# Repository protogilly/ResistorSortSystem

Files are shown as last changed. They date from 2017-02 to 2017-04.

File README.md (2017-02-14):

# ResistorSortSystem
Resistor Sortation System Codebase and Documentation

## Synopsis

This repository contains all the code for my Senior Project, which was a Resistor Sortation System. The finished project accepts resistors within a certain level of straightness at the input, sends them through a stepper-driven feeder that orients and centers them. Next, a servo presses contacts down onto the resistor leads and the machine steps through a ranging process to find the proper configuration to measure the resistor accurately and the contacts are released. After the resistor value is known, a stepper underneath a wheel with receptacles drives until the proper cup is under the dispensing chute. Then another servo is triggered that opens a swing arm releasing the resistor down the chute and into the receptacle.

## Utility to Others

The code in this project contains several snippets that may be useful to users in the future. This project was put on GitHub to make versioning easier for myself, but ultimately will be left online for this purpose. I expect that others may run into similar issues in the future and will attempt to make the code as well-documented as possible for an outsider perspective.

## Motivation

The initial project concept came from seeing containers in one of the University of Memphis’s Engineering Technology labs filled with a of jumbled pile of misshapen resistors of unknown values and wattage ratings with tangled leads. 

This project presented an interesting and challenging Senior Project opportunity, as well as a way to create something useful for both the University Labs and my own personal electronics lab. 

## Platform

The project consists of four parts.

 1. Scripts that run on a Raspberry Pi which speak with controllers on the mainboard over Serial.
 2. The primary program, which runs on a Teensy 3.2. This drives servos, issues commands for steppers, measures resistors, and contains logic that relates these commands to eachother.
 3. A Program that runs on one ATTiny84A which controls the feed stepper. This controller is slaved to the Teensy over I2C and accepts simple commands.
 4. A program that runs on the other ATTiny84A which controls the sort wheel. This controller is also slaved to the Teensy over I2C.

The Raspberry Pi portion is not yet coded, but will be implemented in either Python or C++.
All microcontroller portions are coded using the Arduino codebase and whatever extra drivers are needed for each microcontroller (for example, Teensyduino for the Teensy 3.2).

## Contributors

Until this project is completed at the end of this semester, no external contributors will be allowed. You can, of course, fork the project, but I cannot offer any reasonable support for the project until it has reached a certain state of completion.

## License

This project has no license at the current time. After completion, I will likely move parts of the project into an Open license of some kind, but that is not yet determined.

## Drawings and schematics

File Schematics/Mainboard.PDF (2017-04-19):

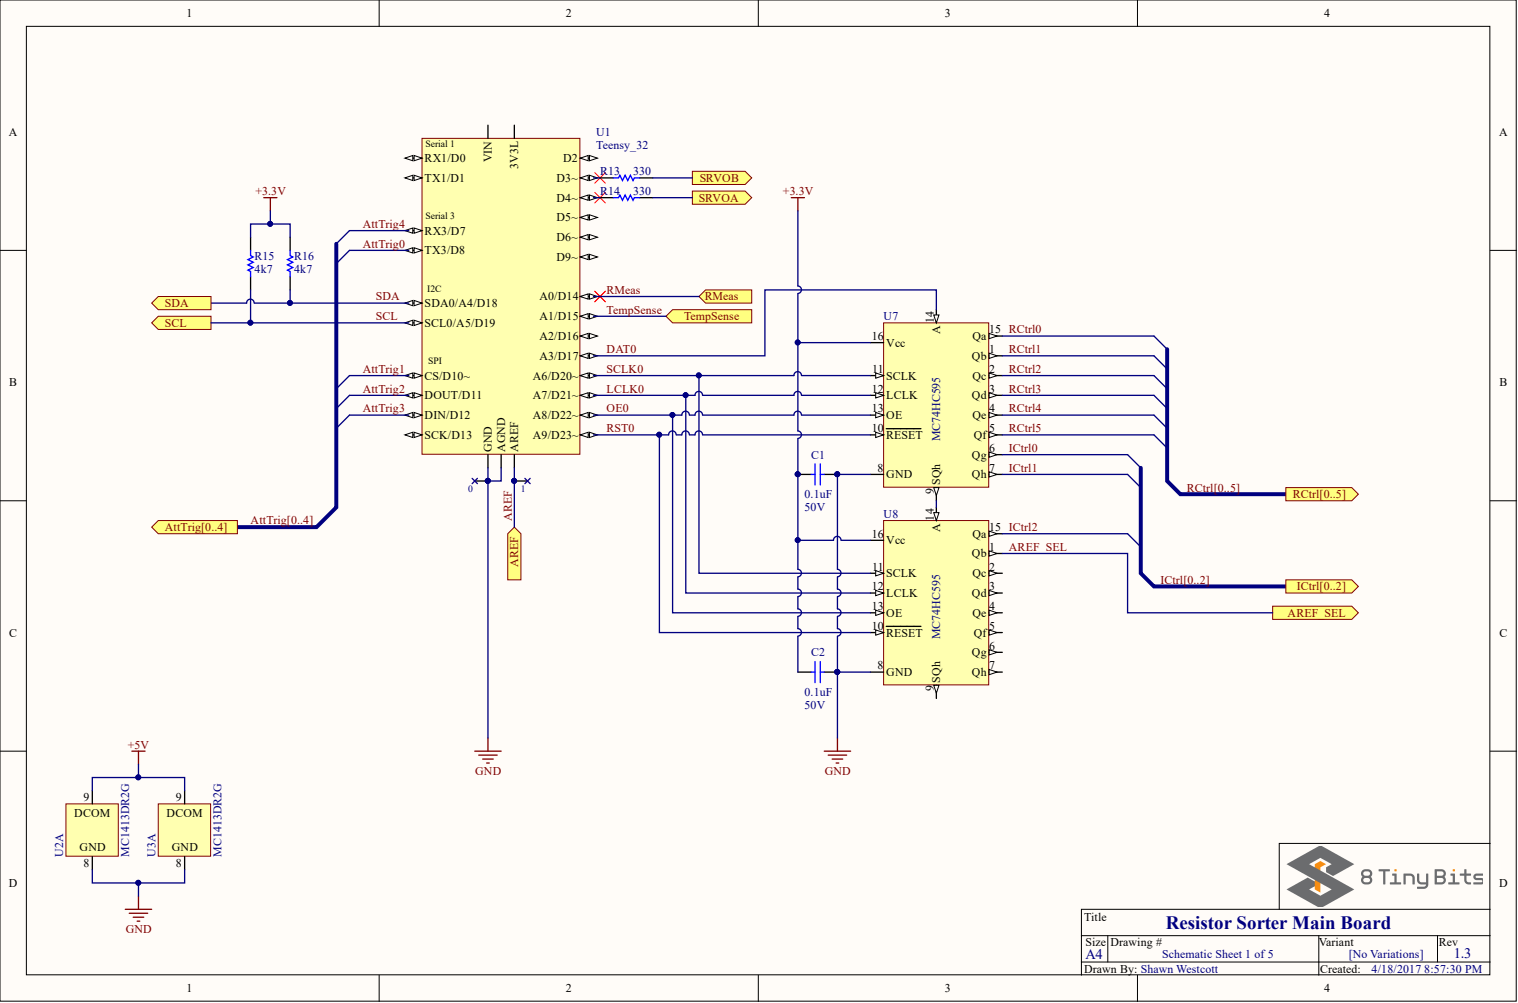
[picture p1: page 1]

Vcc | Q c Q d Q e Q f Q g Q h

SCL K 0 | 1 1 | SCL K LCL K O E RESE T G N D
LCL K 0 | | | 1 2
O E 0 | | | | 1 3
RST 0 | | | | | 1 0

1 1
1 2 | 3
1 3 | 4
1 0

2 | ICtrl[0..2 ]

Draw i n g # Schemat ic Sheet 1 of 5 | Varian t [N o Variat s ]

Created / : 0 PM

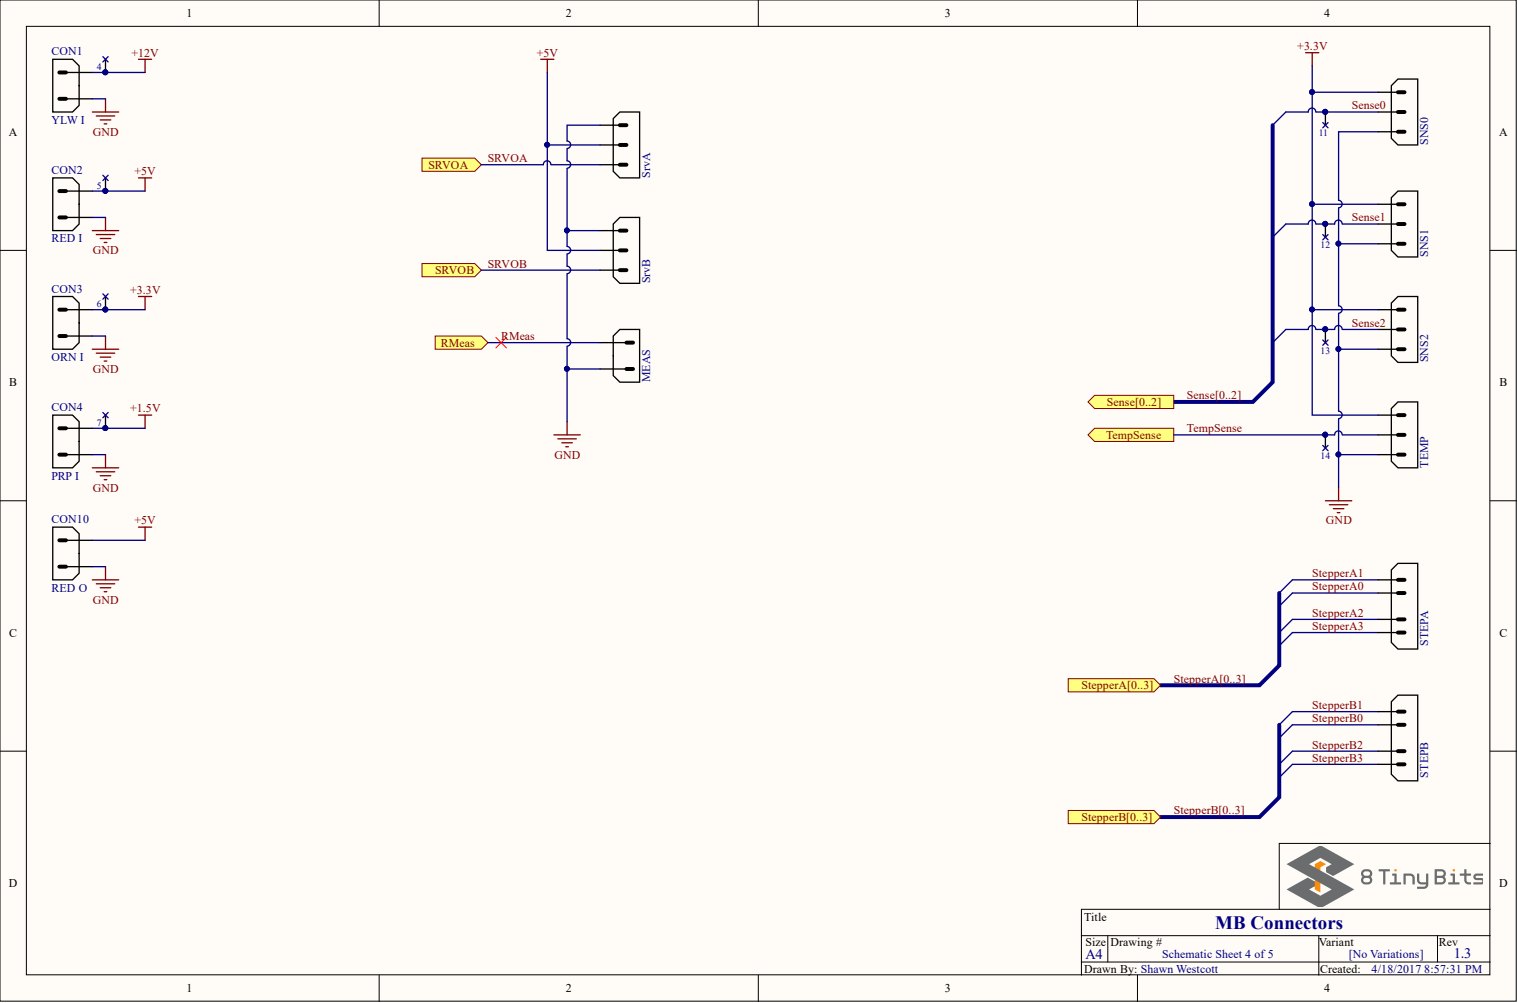
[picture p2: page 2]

MB Connectors Varian

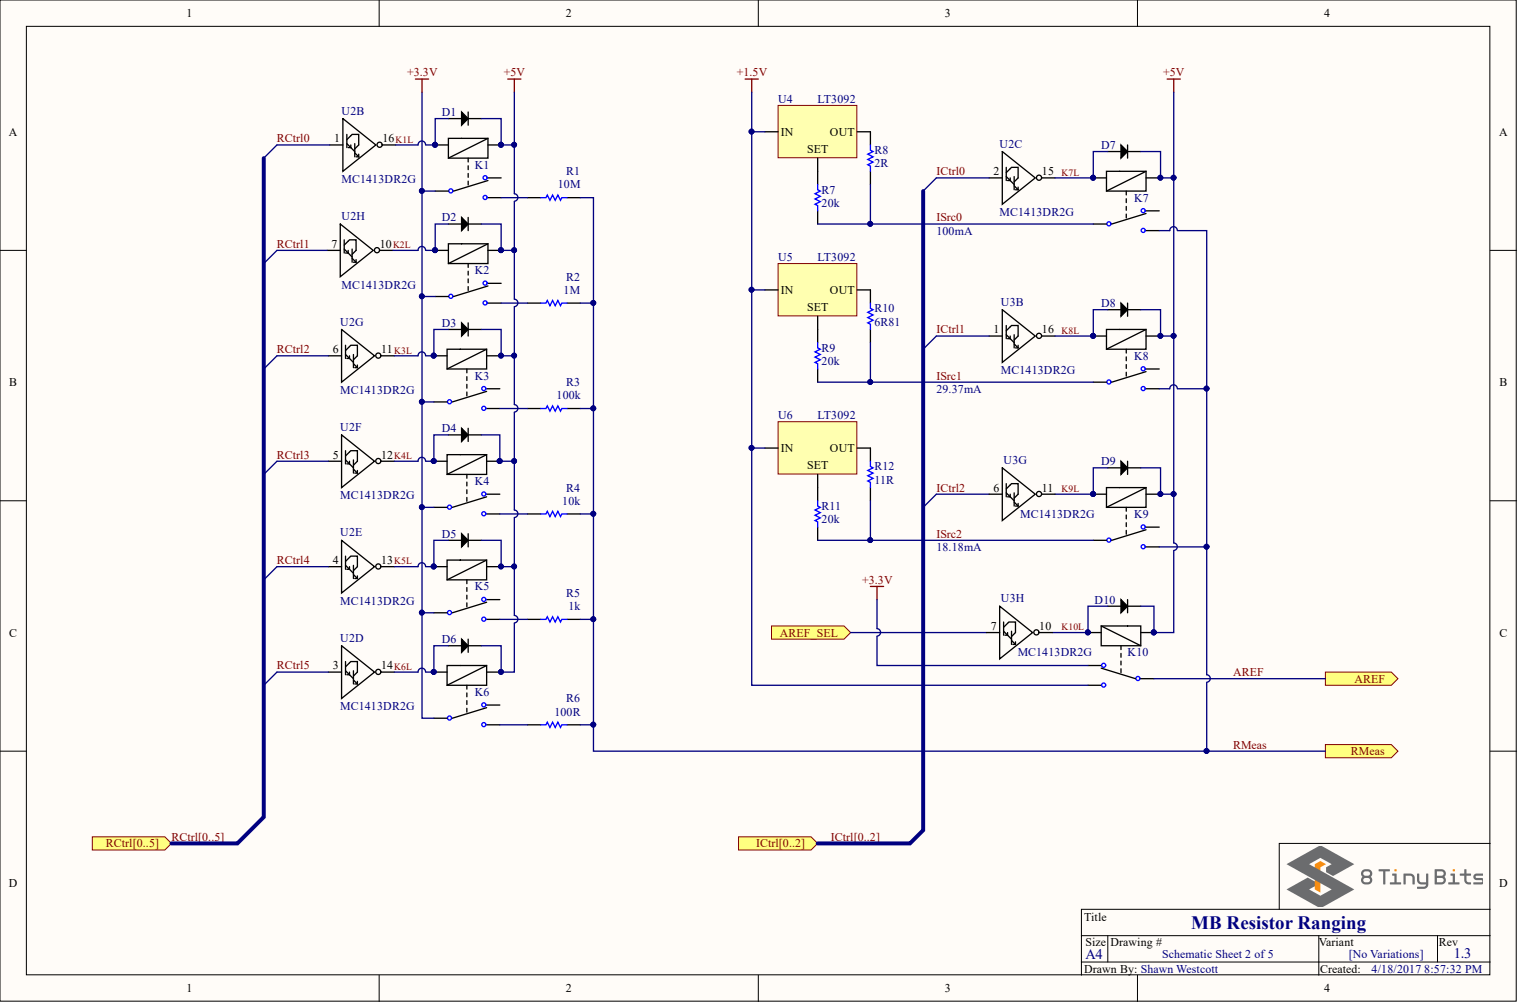
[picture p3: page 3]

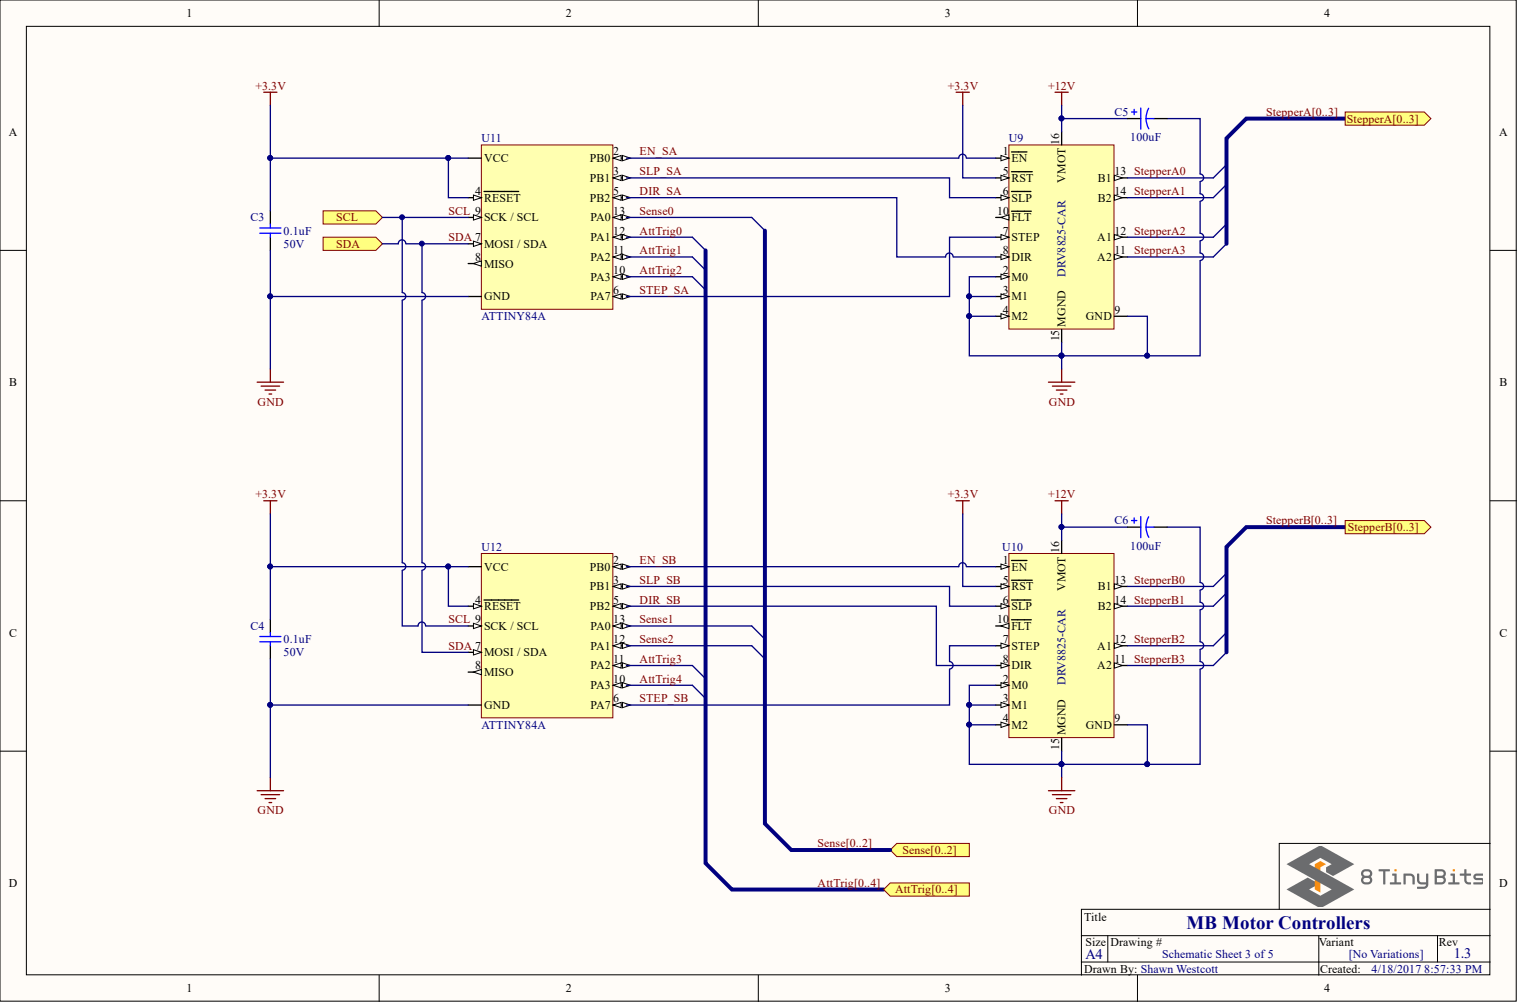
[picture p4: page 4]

SLP_SA | | RST 5
DIR_SA | SLP 6

SDA | MOSI / SDA 7 | | STEP 7

MISO 8

AttTrig1 | DIR 8
AttTrig2 | M0 2

SLP_SB | | RST 5
DIR_SB | SLP 6

AttTrig4 STEP_SB | M0 2

M1 3
M2 4

Size A4 | Schematic Sheet 3 of 5 | Variant [No Variations] | Rev 1.3 Drawing #

Drawn By: Shawn Westcott | | Created: 4/18/2017 8:57:33 PM

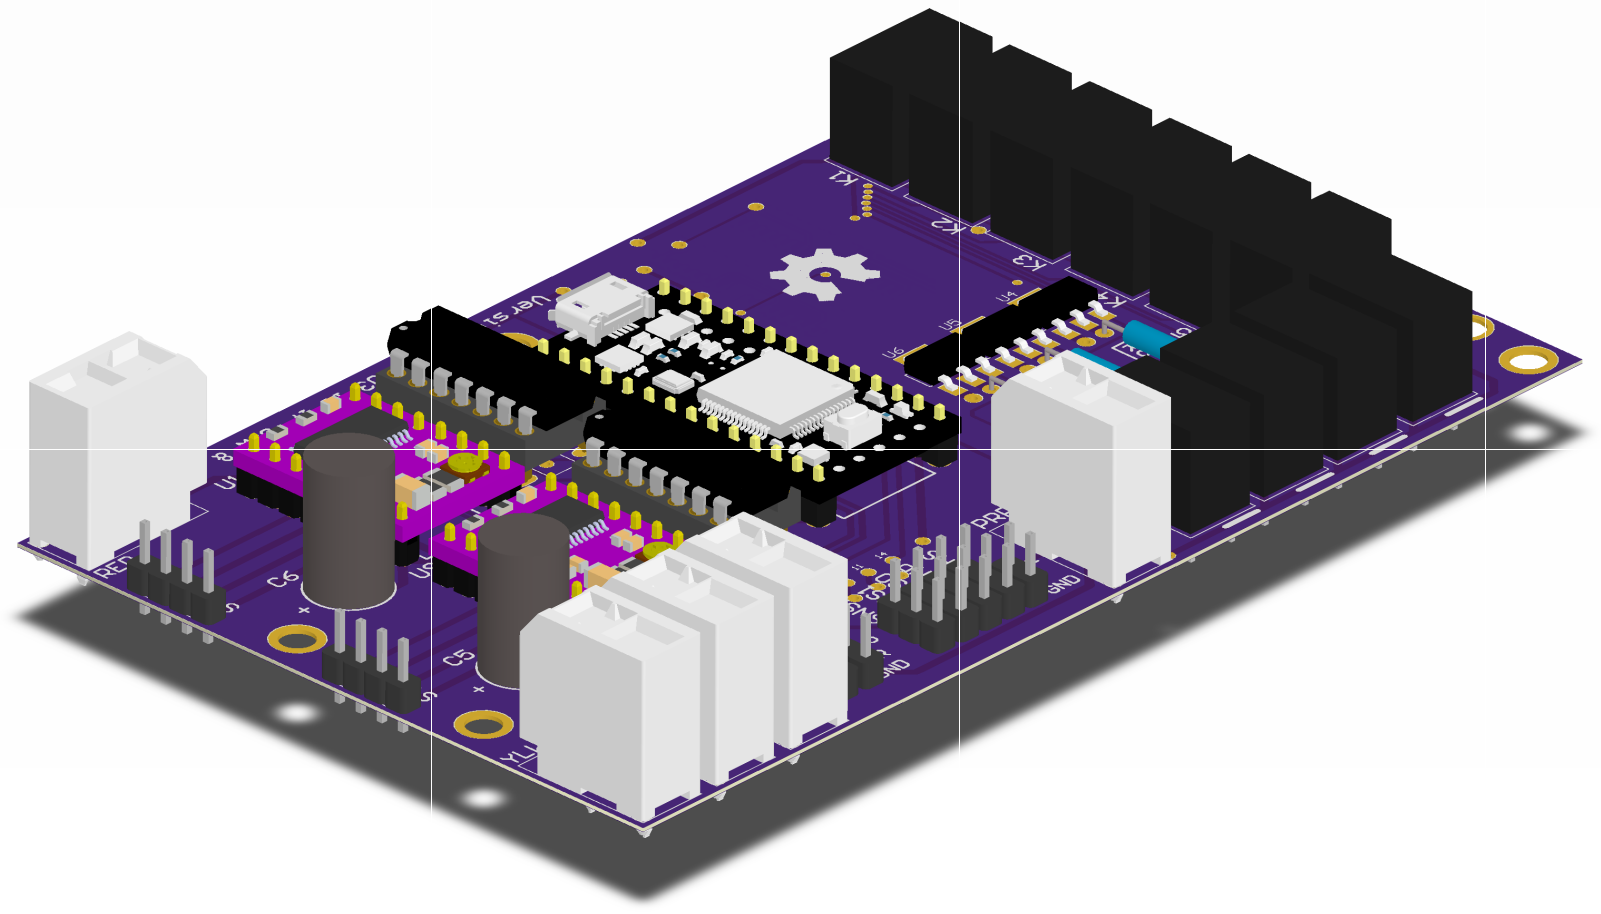
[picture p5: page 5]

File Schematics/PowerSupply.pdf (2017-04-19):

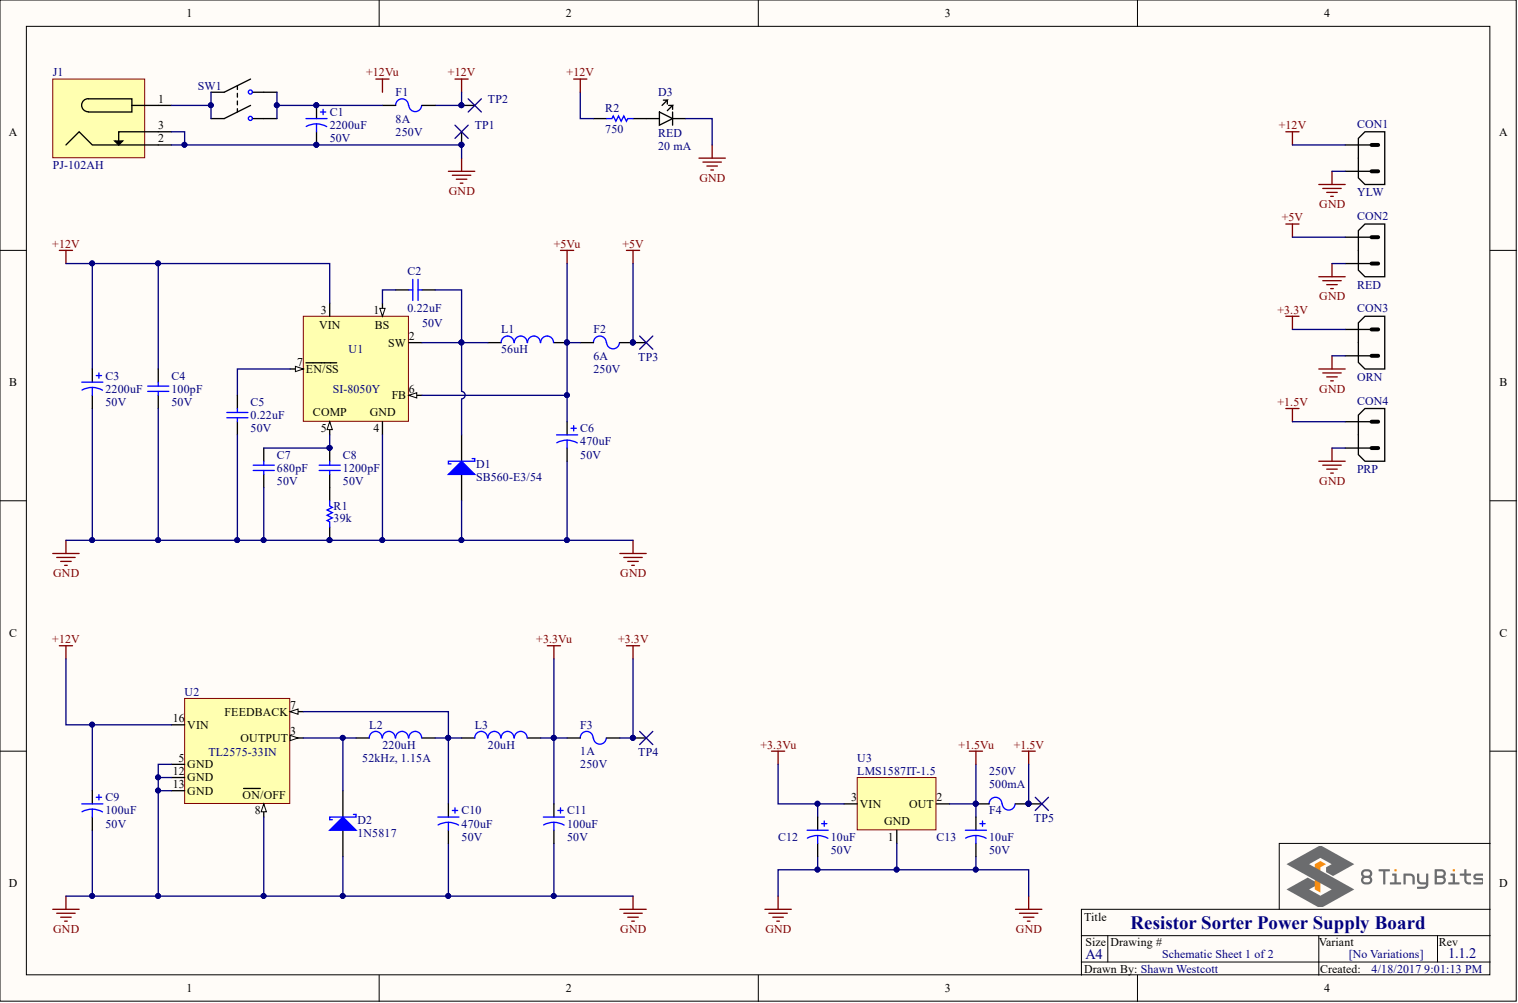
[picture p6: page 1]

Title
Resistor Sorter Power Supply Board Variant

Size A4 | Schematic Sheet 1 of 2 | [No Variations] | Rev 1.1.2 Drawing #

Drawn By: Shawn Westcott | | Created: 4/18/2017 9:01:13 PM

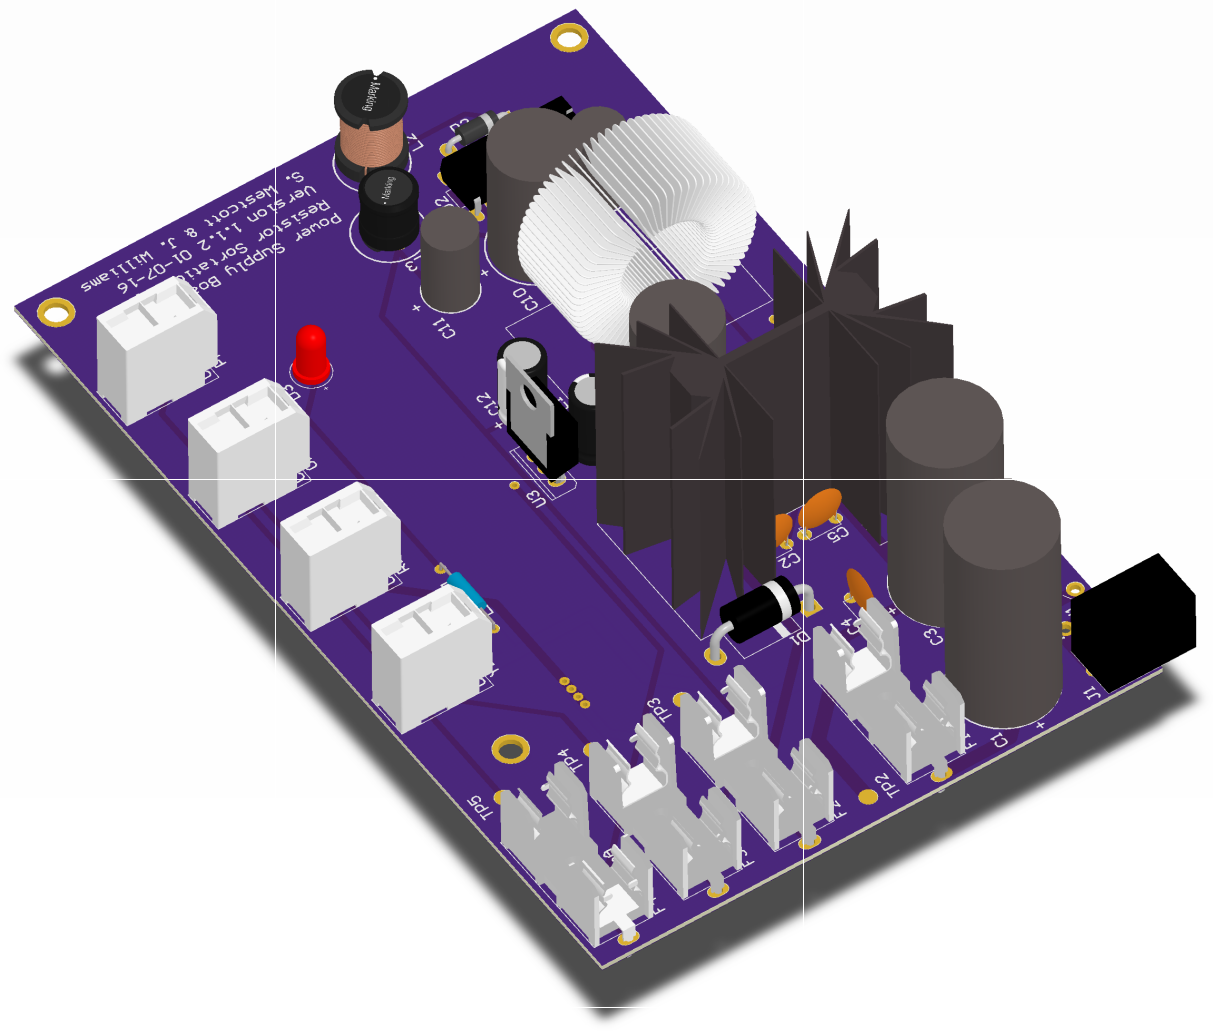
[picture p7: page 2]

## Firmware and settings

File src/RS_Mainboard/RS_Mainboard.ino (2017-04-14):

/*
	RS_Mainboard.ino - Code to control the Mainboard for the Resistor Sortation Project
	Created by Shawn Westcott (www.8tinybits.com), Feb 2017.

	Schematics, Gerbers, and related source code can be found on this project's Github
	https://github.com/slwstctt/ResistorSortSystem

	This code is currently unlicensed and is only available for educational purposes.
	If you'd like to use this code for a non-educational purpose, please contact Shawn
	Westcott (shawn.westcott@8tinybits.com).

	NOTE: This sketch requires a SERIAL1_RX_BUFFER_SIZE and SERIAL1_TX_BUFFER_SIZE of 100
	Make this change in the teensy3 core before trying to use this sketch.

*/

#include <Arduino.h>
#include "ProgmemData.h"

#include <PWMServo.h>
#include <Wire.h>
#include <ShiftRegister74HC595.h>		// See: http://shiftregister.simsso.de/

#include "StepFeed.h"
#include "SortWheel.h"

#include <ADC.h>

// Setting up ADC object
ADC *adc = new ADC();

// Declaring Servos. ContactArm presses contacts onto resistors for measurement, SwingArm releases and retains resistors.
PWMServo ContactArm;
PWMServo SwingArm;

// Init the SortWheel and StepFeed objects
SortWheel Wheel(cupCount, SortController);
StepFeed Feed(FeedController);

// Number of shift registers in circuit
const int srCount = 2;

// Declaring the Shift Register stack.
ShiftRegister74HC595 ShiftReg(srCount, DAT0, SCLK0, LCLK0);

// Shift register states
uint8_t srState[10][srCount] = {
	{B00000000, B00000000},	// Empty
	{B10000000, B00000000},	// 10M Range		NOT USED
	{B01000000, B00000000},	// 1M Range		NOT USED
	{B00000100, B00000000},	// 100k Range
	{B00001000, B00000000},	// 10k Range
	{B00010000, B00000000},	// 1k Range
	{B00100000, B00000000},	// 100R Range
	{B00000010, B01000000},	// 100mA Source	NEEDS CALIBRATION
	{B00000001, B01000000},	// 29.37mA Source	NEEDS CALIBRATION
	{B00000000, B11000000} 	// 18.18mA Source	NEEDS CALIBRATION
};

// These variables keep track of states of slave processors.
volatile bool feedInProcess = false;
volatile bool sortMotionInProcess = false;

// Maximum Analog Value, calculated at setup.
int maxAnalog = 0;

// State Machine Variable
int cState = 0;

// Global rep of measurement data
double measurement = 0.0;

// Bool set when feeding out the remainder of the feed stack
bool feedToEnd = false;
bool isQCR = false;

void setup() {
	// Init Servos
	ContactArm.attach(SrvoA);
	SwingArm.attach(SrvoB);

	// Home the Servos
	SwingArm.write(swingHome);
	ContactArm.write(contactHome);

	// Setting up various pins
	pinMode(OE0, OUTPUT);
	pinMode(RST0, OUTPUT);
	pinMode(AttTrig0, INPUT_PULLUP);	// Trigger from Sort Controller indicating last command completed successfully
	pinMode(AttTrig1, OUTPUT);
	pinMode(AttTrig2, OUTPUT);
	pinMode(AttTrig3, INPUT_PULLUP);	// Trigger from Feed Controller indicating last command completed successfully
	pinMode(AttTrig4, OUTPUT);
	pinMode(ledPin, OUTPUT);

	// AttTrig3 is an interrupt from the slave processor that lets us know the last feed command is complete.
	attachInterrupt(AttTrig3, isrFeedClear, RISING);

	// AttTrig0 is an interrupt from the slave processor that lets us know the last sort move command is complete.
	attachInterrupt(AttTrig0, isrWheelClear, RISING);

	// Reset and enable output on the shift register
	clearRegisters();
	digitalWrite(OE0, LOW);		// Output Enable is Active-low
	digitalWrite(ledPin, HIGH);

	// I2C Wire init
	Wire.begin();

	// Wait 100ms just to make sure the Feed Controller is finished with setup before sending it data
	delay(100);

	// Send setup value to StepFeeder controller
	Wire.beginTransmission(FeedController);
	
	// Number of steps per feed action = 115 degrees, 1.8 deg/step = ~64 steps per action.
	Wire.write(64);
	Wire.endTransmission();
	
	// Set up ADC
	adc->setReference(ADC_REF_EXT);
	adc->setResolution(bitPrecision);
	adc->setAveraging(32);
	maxAnalog = adc->getMaxValue();
	adc->setSamplingSpeed(ADC_VERY_LOW_SPEED);
	adc->setConversionSpeed(ADC_VERY_LOW_SPEED);

	// Begin Serial comms with RPi
	Serial.begin(9600);

	// Wait for the Ready from the RPi.
	do {
		;
	} while (!cmdReady());

	String incCmd = Serial.readString();
	Command handshake = parseCmd(incCmd);

	if (handshake.cmd == "RDY") {
		digitalWrite(ledPin, LOW);
	} else {
		sendError("Inv Handshake on Startup. Halting.");
		while (true) { ; }	// Something went very wrong. Stop here.
	}
}

void loop() {

	Command thisCommand;

	// At the start of every loop, check if a command is waiting.
	if (cmdReady()) {
		String incCmd = Serial.readString();
		thisCommand = parseCmd(incCmd);

		if (cState == 0) {
			// Some command handling...
			if (thisCommand.cmd == "MAJ") {
				// "Major Divisions" is a common preset.
				int precisionPercent = thisCommand.args[0].toInt();
				double precision = (precisionPercent / 100.0);

				// Each cup gets a range of 10 up to 82, in powers of 10 (82 is the high side standard resistance value at the highest precision)
				for (int i = 0; i < 6; i++) {
					double lowSide = pow(10.0, i);
					double highSide;

					// Fetch high side value based on precision
					if (precisionPercent == 1) {
						highSide = (lowSide * stdResistors1[E96Count - 1]) / 100.0;
					} else if (precisionPercent == 2 || precisionPercent == 5) {
						highSide = (lowSide * stdResistors2_5[E24Count - 1]) / 100.0;
					} else {
						highSide = (lowSide * stdResistors10[E12Count - 1]) / 100.0;
					}

					Wheel.cups[i].setCupRange(getMin(lowSide, precision), getMax(highSide, precision));
					Wheel.cups[i].setRejectState(false);
				}

				// Upper end cups are rejects for this range.
				Wheel.cups[6].setRejectState(true);
				Wheel.cups[7].setRejectState(true);
				Wheel.cups[8].setRejectState(true);
				Wheel.cups[9].setRejectState(true);

				sendAck();
			}

			if (thisCommand.cmd == "DIV") {
				// "Simple Division" -- we get a number of groups to divide into, a precision, and a range of typical values.

				// TODO: This stuff.

				sendAck();
			}

			if (thisCommand.cmd == "SGL" || thisCommand.cmd == "QCR") {
				// "Single Resistance" -- We search a collection of resistors for a specific value within a given precision.
				// "Quality Check" -- Effectively the same as searching for a single resistance, except we set a flag to send measurement data.

				int precision = thisCommand.args[0].toInt();
				double nominal = thisCommand.args[1].toFloat();

				// To do this, we simply set one cup to take this value, and the rest become rejects.
				Wheel.cups[0].setCupRange(nominal, precision);
				Wheel.cups[0].setRejectState(false);

				for (int i = 1; i < cupCount; i++) {
					Wheel.cups[i].setRejectState(true);
				}

				if (thisCommand.cmd == "QCR") {
					isQCR = true;
				}

				sendAck();

			}

			if (thisCommand.cmd == "SSR") {
				// "Sortable Range" -- we get a precision and 9 typical values. The 10th is reject.
				int precision = thisCommand.args[0].toInt();

				// Loop through the list of arguments setting up cups
				for (int i = 1; i < thisCommand.numArgs; i++) {
					Wheel.cups[i].setCupRange(thisCommand.args[i].toFloat(), precision);
					Wheel.cups[i].setRejectState(false);
				}

				Wheel.cups[9].setRejectState(true);

				sendAck();

			}

			if (thisCommand.cmd == "OHM") {
				// "Ohmmeter mode" -- We set all cups to accept all resistors. Since we always send measurement data back, there's no need to do much else.

				for (int i = 0; i < cupCount; i++) {
					Wheel.cups[i].setCupRange(0.0, 1000000000.0);
					Wheel.cups[i].setRejectState(false);
				}

				sendAck();

			}

			if (thisCommand.cmd == "CUP") {
				// "Cup set" command sets a cup to a specific value.
				int cupNum = thisCommand.args[0].toInt();
				double minVal = thisCommand.args[1].toFloat();
				double maxVal = thisCommand.args[2].toFloat();

				bool isReject;

				if (thisCommand.args[3].toInt() == 0) {
					isReject = false;
				} else {
					isReject = true;
				}

				// Convert to 0-index
				cupNum--;

				Wheel.cups[cupNum].setCupRange(minVal, maxVal);
				Wheel.cups[cupNum].setRejectState(isReject);

				sendAck();

			}
		}
	}

	// The loop is a state machine, the action the system takes depends on what state it is in.
	if (cState == 0) {
		// Waiting for SRT.	
		if (thisCommand.cmd == "SRT") {
			cState = 1;
			sendReady();
		}
	} else if (cState == 1) {
		// Sorting Mode (Waiting on NXT).
		// NXT is the command that indicates the user has pressed the button saying they loaded a resistor.
		if (thisCommand.cmd == "NXT") {

			if (feedInProcess) {
				sendError("Feed In Process");
				return;
			} else if (!Feed.loadPlatformEmpty()) {
				sendError("Load Platform Not Empty");
				return;
			} else {
				Feed.load();
				cState = 2;		// Feed Process
				sendAck();
				return;
			}
		}

		// End is the user requesting that we cycle to completion.
		if (thisCommand.cmd == "END") {
			feedToEnd = true;
			cState = 2;			// Feed Process
			sendAck();
			return;
		}

	} else if (cState == 2) {
		// Resistor Feeding
		if (Feed.loadPlatformEmpty()) {
			// If the feed platform is empty, but we're in a motion, wait.
			if (feedInProcess) {
				return;
			}

			// If we're not feeding to the end after waiting, we're clear for a new command.
			if (!feedToEnd) {
				cState = 1;		// Ready for next command
				sendReady();
				return;
			}
		}

		// Because of returns, we only get to this point if the load platform is full.
		// Structuring in this way allows a states where we are feeding to the end to fall through to this point.

		if (!Feed.measurePlatformEmpty()) {
			// If the measurement platform is full, we have to handle that first.
			cState = 3;				// Measure Resistor
		} else {
			if (Feed.feedEmpty()) {
				// If the feed is empty, we must be ready.
				if (feedToEnd) {
					cState = 0;			// Finished.
					isQCR = false;			// In case we were in QCR, reset it.
					feedToEnd = false;
					sendDone();
				} else {
					cState = 1;			// Ready for next command
					sendReady();
				}
			} else {
				// Otherwise, cycle the feed and mark the motion in process.
				Feed.cycleFeed(1);
				feedInProcess = true;
			}
		}

		return;

	} else if (cState == 3) {
		// Measure Resistor
		if (!Feed.measurePlatformEmpty()) {
			// If the measurement platform isn't empty, measure the resistor
			measurement = measureResistor();

			// Get the target cup and begin the sort motion
			int targetSortPos = getTargetCup(measurement);

			// Report the measurement
			Command measurementData;
			measurementData.cmd = "MES";
			measurementData.numArgs = 2;
			measurementData.args[0] = String(targetSortPos);
			measurementData.args[1] = String(measurement, 4);
			sendCommand(measurementData);

			// Move the sort wheel.
			Wheel.moveTo(targetSortPos);
			sortMotionInProcess = true;
			cState = 4;				// Dispense Resistor
		} else {
			// If it's empty, we either need to go back to feeding or attempt dispense again.
			if (sortMotionInProcess) {
				cState = 4;			// Dispense Resistor
			} else {
				cState = 2;			// Feed Process
			}
		}

		return;

	} else if (cState == 4) {
		// Dispense Resistor
		if (!sortMotionInProcess) {
			// A dispense state occurs after a sort motion has begun. Wait for the sort motion to complete and dispense. EZPZ.
			SwingArm.write(swingOpen);
			delay(swingTime);			// actual delay here, since we shouldn't move or process anything else until we're sure this is clear.
			Feed.dispense();
			SwingArm.write(swingHome);
			delay(swingTime);
			cState = 2;				// Feed Process
		}
	}
}

void isrFeedClear() {
	feedInProcess = false;
	digitalWrite(ledPin, LOW);
}

void isrWheelClear() {
	sortMotionInProcess = false;
	digitalWrite(ledPin, LOW);
}

Command parseCmd(String incCmd) {
	// parses a command string into the Command struct. Also handles certain vital commands, such as Halt.
	
	Command output;
	
	// Start by deleting the verification bit
	incCmd.remove(0, 1);

	// Fetch the first 3 characters and delete them, with the semicolon.
	output.cmd = incCmd.substring(0, 3);
	incCmd.remove(0, 4);

	int argIndex = 0;
	int commaIndex = incCmd.indexOf(',');

	// Fetch all args until there are no delimiters left
	while (commaIndex != -1) {
		output.args[argIndex] = incCmd.substring(0, commaIndex);
		incCmd.remove(0, commaIndex + 1);
		argIndex++;
	}

	// The rest of the string is the last arg.
	output.args[argIndex] = incCmd;
	output.numArgs = argIndex + 1;

	// Commands that follow are Debug commands, which are handled immediately.

	// Halt command recieved. Requires reset.
	if (output.cmd == "HCF") {
		sendAck();
		while (1) { ; }
	}

	 // Always ACK a RDY.
	 if (output.cmd == "RDY") {
	    sendAck();
	 }

	// Debugging command: Cycle Feed
	if (output.cmd == "CFD") {
		int numCycles = output.args[0].toInt();
		Feed.cycleFeed(numCycles);
		digitalWrite(ledPin, HIGH);
		sendAck();
	}

	// Debugging command: Move Sort Wheel
	if (output.cmd == "MSW") {
		int targetCup = output.args[0].toInt();
		Wheel.moveTo(targetCup);
		digitalWrite(ledPin, HIGH);
		sendAck();
	}

	// Debugging command: Cycle Dispense Arm
	if (output.cmd == "CDA") {
		digitalWrite(ledPin, HIGH);
		SwingArm.write(swingOpen);
		delay(swingTime);
		SwingArm.write(swingHome);
		delay(swingTime);
		digitalWrite(ledPin, LOW);
		sendAck();
	}

	// Debugging command: Test Measurement
	if (output.cmd == "TME") {
		sendAck();

		// Get the current cup and attempt a measurement
		double testMeasurement = measureResistor();
		int thisCup = Wheel.getCurrentPosition();

		// Construct a response
		Command mesCmd;
		mesCmd.cmd = "MES";
		mesCmd.numArgs = 2;
		mesCmd.args[0] = String(thisCup);
		mesCmd.args[1] = String(testMeasurement);

		// Send the measurement data
		sendCommand(mesCmd);

	}

	 if (output.cmd == "RST") {
	    sendAck();
	    _reboot_Teensyduino_();
	 }

	return(output);
}

String parseCmd(Command outCmd) {
	// parses a Command struct into a command string for sendout.

	String output;
	output = outCmd.cmd;
	output += ";";

	for (int i = 0; i < outCmd.numArgs; i++) {
		output += outCmd.args[i];
		output += ",";
	}

	// Delete the last character in the string
	if (outCmd.numArgs > 0) {
		output = output.substring(0, output.length() - 1);
	}

	int verifyValue = output.length() + 1;

	char lenVerify = (char)verifyValue;
	output = lenVerify + output;

	return(output);
}

bool cmdReady() {
	// The first byte of a command will be the number of bytes in the command.
	bool result = ((int) Serial.peek() == (int)Serial.available());
	return(result);
}

void sendCommand(Command sendCmd) {
	String output = parseCmd(sendCmd);

	Serial.println(output);
	Serial.flush();
}

void sendError(String err) {
	// Sends an error to the RPi

	Command errCommand;

	errCommand.cmd = "ERR";
	errCommand.numArgs = 1;
	errCommand.args[0] = err;

	sendCommand(errCommand);
}

void sendDat(String dat) {
	// Sends misc data to the RPi

	Command datCommand;

	datCommand.cmd = "DAT";
	datCommand.numArgs = 1;
	datCommand.args[0] = dat;

	sendCommand(datCommand);
}

void sendReady() {
	Command readyCommand;

	readyCommand.cmd = "RDY";
	readyCommand.numArgs = 0;

	sendCommand(readyCommand);
}

void sendDone() {
	Command doneCommand;

	doneCommand.cmd = "DON";
	doneCommand.numArgs = 0;

	sendCommand(doneCommand);
}

void sendAck() {
	Command ackCommand;

	ackCommand.cmd = "ACK";
	ackCommand.numArgs = 0;

	sendCommand(ackCommand);
}

void clearRegisters() {
	// This function triggers the reset on the shift registers, then latches the empty register.

	digitalWrite(RST0, LOW);	// RESET is Active-low
	delay(1);
	digitalWrite(RST0, HIGH);

	// Going LO-HI-LO ensures a rising edge is seen, then the latch clock is set back to the expected rest state (LOW).
	digitalWrite(LCLK0, LOW);
	delay(1);
	digitalWrite(LCLK0, HIGH);
	delay(1);
	digitalWrite(LCLK0, LOW);
}

double measureResistor() {
	// This function completes a full measurement cycle and returns a resistance in Ohms.
	// 0.0 represents a rejected resistor.
	
	ContactArm.write(contactTouch);
	delay(contactTime);
	
	int medianReading = maxAnalog / 2;
	int cDifference = 99999;
	int bestDifference = 99999;		// Arbitrarily large value here to ensure any reading is superior.
	int bestRange = 0;							// Range 0 is with outputs turned off, a safe fallback in case of failure.
	double bestReading = 0.0;
	double reading = 0.0;
	long readingSums = 0;
		
	// For each range...
	for (int i = 3; i <= 7; i++) {
		
		// Enable the outputs for testing this range and take a measurement.
		ShiftReg.setAll(srState[i]);
		delay(50);							// 5ms maximum operating time for relays, x10 for safety.

		int goodCount = 0;
		int count = 0;
		bool testComplete = false;

		// Try to get 30 good measurements, but give up after 100 attempts.
		while (!testComplete) {
			count++;
			int thisReading = adc->analogRead(RMeas);
			double thisResistance = getResistance(thisReading, i);

			// If the resistance is in an acceptable range, it's good
			if (thisResistance < maxAccepted && thisResistance > 0.5) {
				readingSums = readingSums + thisReading;
				goodCount++;
			}

			if (count > 100) {
				testComplete = true;
			}

			if (goodCount > 30) {
				testComplete = true;
			}
		}

		if (goodCount == 0) {
			reading = 0.0;
		} else {
			// Average the measurements
			reading = (double) readingSums / (double) goodCount;
		}

		cDifference = reading - medianReading;
		cDifference = (cDifference < 0) ? -cDifference : cDifference;	// Absolute value

		// If this is better than the current best, make this the best.
		if (cDifference < bestDifference) {
			bestRange = i;
			bestDifference = cDifference;
			bestReading = reading;
		}
	}

	// Convert the final result to a resistance.
	double result = getResistance(bestReading, bestRange);

	// Return to home position after measurement made.
	ContactArm.write(contactHome);
	delay(contactTime);
	ShiftReg.setAll(srState[0]);
	
	// Return the Ohms value.
	return(result);
}

double getResistance(double measurement, int range) {
	// This function returns a resistance from a given measurement in a given range.

	double result = 0.0;

	// Do not calculate resistances in the cutoff bands.
	if (measurement < adcLCutoff || measurement > adcHCutoff) {
		return(result);
	}

	// Range needs to change into a 0 index (typically it is 1-indexed.)
	range--;

	// 6, 7, and 8 are the current source ranges. 0-5 are Volt Divider ranges
	if (range < 6) {
		// First, convert the reading to volts. (High voltage for dividers)
		double vReading = measurement * (avHigh / maxAnalog);

		// Voltage divider formula solved for R2...
		result = (internalTestResistances[range] * vReading) / (avHigh - vReading);

	} else {
		// Bring the range down to 0 index from 6-8 index
		range = range - 6;

		//Convert the reading to volts. (Low voltage for current sources)
		double vReading = measurement * (avLow / maxAnalog);

		// Current source measurement is simple, V=IR, solving for R gives R=V/I
		result = vReading / internalCurrentSources[range];
	}

	return(result);
}

double getMin(double nominal, double precision) {
	double diff = nominal * precision;
	return(nominal - diff);
}

double getMax(double nominal, double precision) {
	double diff = nominal * precision;
	return(nominal + diff);
}

int getTargetCup(double measurement) {
	// This function checks the measurement against every non-reject cup. If a home is found, that cup number (not index) is returned.
	
	for (int i = 0; i < cupCount; i++) {
		// For each cup, look for a valid home that is not a reject.
		if (Wheel.cups[i].canAccept(measurement) && !(Wheel.cups[i].isReject())) {
			int result = i + 1;
			return(result);	// Return that cup.
		}
	}

	for (int i = 0; i < cupCount; i++) {
		// Find the first available reject cup.
		if (Wheel.cups[i].isReject()) {
			int result = i + 1;
			return(result);	// Return that cup.
		}
	}

	sendError("No Valid Cup Found");
	return(-1);
}

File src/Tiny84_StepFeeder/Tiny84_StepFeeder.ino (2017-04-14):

/*
	Tiny84_StepFeeder.ino - StepFeeder controller for the Resistor Sortation Project 
	Created by Shawn Westcott (www.8tinybits.com), Feb 2017.

	Schematics, Gerbers, and related source code can be found on this project's Github
	https://github.com/slwstctt/ResistorSortSystem

	This code is currently unlicensed and is only available for educational purposes.
	If you'd like to use this code for a non-educational purpose, please contact Shawn
	Westcott (shawn.westcott@8tinybits.com).
*/

#define I2C_SLAVE_ADDRESS 0x2

#include <TinyWireS.h>
#include <AccelStepper.h>

#ifndef TWI_RX_BUFFER_SIZE
#define TWI_RX_BUFFER_SIZE (1)
#endif

// Pin Definitions
const int pinStep = 7;
const int pinDir = 8;
const int pinSleep = 9;
const int pinEnable = 10;
const int attTrig3 = 2;

// volatiles for I2C control
volatile bool hasSetup = false;	// Whether or not the controller has recieved a setup command
volatile bool inMotion = false;	// Whether or not a motion is in progress.
volatile uint8_t fwdSteps = 0;	// Number of steps for a step feed motion.
volatile uint8_t cycleCount = 0;	// Number of full step cycles to execute.

AccelStepper stepFeeder(1, pinStep, pinDir);

void setup() {
	// Stepper Enable pin is inverted.
	stepFeeder.setPinsInverted(false, false, true);

	// Start I2C comms.
	TinyWireS.begin(I2C_SLAVE_ADDRESS);
	TinyWireS.onReceive(receiveEvent);

	// Setup Output pins
	pinMode(pinSleep, OUTPUT);
	pinMode(attTrig3, OUTPUT);

	// TODO: Implement Sleep mode
	digitalWrite(pinSleep, HIGH);

	// Setup stepper settings.
	stepFeeder.setEnablePin(pinEnable);
	stepFeeder.setMaxSpeed(400.0);
	stepFeeder.setAcceleration(270.0);

	// Turn off the stepper motor on startup to save energy.
	stepFeeder.disableOutputs();
}

void loop() {
	if (inMotion) {
		if (cycleCount > 0) {
			// If there are cycles left to execute, do so.
			stepCycle();
			cycleCount--;
		} else {
			// Otherwise, turn off the flag and send a trigger to the master
			inMotion = false;
			digitalWrite(attTrig3, HIGH);
			tws_delay(10);
			digitalWrite(attTrig3, LOW);

			// Turn off the stepper to save energy between actions.
			stepFeeder.disableOutputs();
		}
	}

	// Continual check for new I2C commands.
	TinyWireS_stop_check();
}

void receiveEvent(uint8_t howMany) {
	if (howMany < 1 || howMany > TWI_RX_BUFFER_SIZE) {
		return;
	}

	uint8_t uCount = TinyWireS.receive();

	if (!hasSetup) {
		// If we haven't recieved a setup yet, this must be it. Set the number of steps per feed action.
		fwdSteps = uCount;
		hasSetup = true;
	} else {
		// Otherwise, this must be a command to move a certain number of cycles. Turn on the stepper motor and start the motion.
		cycleCount = uCount;

		// First, though, a sanity check. We'll never cycle more than 10 times.
		if (cycleCount > 10) {
			return;
		}
		
		stepFeeder.enableOutputs();
		inMotion = true;
	}
}

void stepCycle() {
	// Executes one step cycle.

	stepFeeder.move(fwdSteps);

	// Note: runToPosition is a blocking command, and is only appropriate here because the master waits on a trigger to send each command.
	stepFeeder.runToPosition();

	tws_delay(5);		// Delays exist here to allow a braking effect between actions.

	// A step cycle contains a forward and a reverse motion. The reverse motion is just the opposite of a forward motion.
	stepFeeder.move(-fwdSteps);
	stepFeeder.runToPosition();

	tws_delay(5);
}

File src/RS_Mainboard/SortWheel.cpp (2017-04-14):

/*
SortWheel.cpp - An object for representing the sortation wheel and its cups
Created by Shawn Westcott (www.8tinybits.com), Feb 2017.

Schematics, Gerbers, and related source code can be found on this project's Github
https://github.com/slwstctt/ResistorSortSystem

This code is currently unlicensed and is only available for educational purposes.
If you'd like to use this code for a non-educational purpose, please contact Shawn
Westcott (shawn.westcott@8tinybits.com).

*/

#include "Arduino.h"
#include <Wire.h>
#include "SortWheel.h"

SortWheel::SortWheel(int numCups, int wireChannel) {
	_wireChannel = wireChannel;
	_numCups = numCups;
	_curPos = 1;
}

int SortWheel::getCurrentPosition() {
	return(_curPos);
}

void SortWheel::moveTo(int target) {
	int rightPath = 0;
	int leftPath = 0;
	int bestRoute = 0;

	if (_curPos < target) {
		rightPath = target - _curPos;
		leftPath = _numCups - target + _curPos;
	} else {
		rightPath = _numCups - _curPos + target;
		leftPath = _curPos - target;
	}

	bestRoute = rightPath < leftPath ? rightPath : -leftPath;

	// We'd like to only ever send a single byte.
	uint8_t route = 0;

	// We know we'll never send a very large value. Negative numbers can start at +100.
	if (bestRoute < 0) {
		bestRoute = bestRoute * -1;
		bestRoute = bestRoute + 100;
	}
	route = (uint8_t) bestRoute;

	Wire.beginTransmission(_wireChannel);
	Wire.write(route);
	Wire.endTransmission();

	_curPos = target;
}

SortCup::SortCup() {
	
	_minVal = 0.0;
	_maxVal = 0.0;
	_rejectCup = true;
}

SortCup::SortCup(double minValue, double maxValue) {
	
	this->setCupRange(minValue, maxValue);
	_rejectCup = false;
}

SortCup::SortCup(double nominal, int precision) {

	this->setCupRange(nominal, precision);
	_rejectCup = false;
}

double SortCup::getMin() {
	return(_minVal);
}

double SortCup::getMax() {
	return(_maxVal);
}

bool SortCup::canAccept(double value) {
	int iVal = (int) value;

	if (value <= _maxVal && value >= _minVal) {
		return(true);
	} else {
		return(false);
	}

	if (this->isReject()) {
		return(true);
	}
}

bool SortCup::isReject() {
	return(_rejectCup);
}

void SortCup::setRejectState(bool state) {
	_rejectCup = state;
}

void SortCup::setCupRange(double minValue, double maxValue) {

	_minVal = minValue;
	_maxVal = maxValue;
}

void SortCup::setCupRange(double nominalValue, int precisionPercent) {
	double range = nominalValue * ((double) precisionPercent / 100.0);

	_minVal = nominalValue - range;
	_maxVal = nominalValue + range;
}

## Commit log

2017-02-14 Pre-Existing Work
    This is most of the pre-existing work (Gerbers, schematics). Still
    remaining: Schematics for sensor board and power supply board.
    [HESense.GBL, HESense.GBO, HESense.GBP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]
2017-02-14 Formatting
    One change slipped by.
    [RS_Mainboard.ino]
2017-02-14 Added dispenseResistor function
    added function that drops a resistor from the test platform.
    Additionally, naming convention fix on feedResistor function.
    [RS_Mainboard.ino]
2017-02-15 Loop Logic Started
    moved bulky definitions and consts to header and cpp file. some new
    documentation added. Fixed errors in feed logic (incorrect comparison in
    for loop, forgot to assign shifted value).
    [ProgmemData.h, RS_Mainboard.ino]
2017-02-15 TODO for Resistor Measurement
2017-02-16 Began work on resistor measurement function
    TODO: algorithm to check positive contact, conversion to Ohms
2017-02-16 Bugfixes and corrections from last commit
    various fixes (missing semicolons, various errors) from last commit (was
    typed in a rush).
    [RS_Mainboard.ino]
2017-02-16 Math Correction
    Fixed mistake causing incorrectly calculated voltage.
    [RS_Mainboard.ino]
2017-02-16 Added logic for cycling the resistor on NEXT cmd
2017-02-19 SortWheel header
    Added the SortWheel header and class to manage the sort wheel in a more
    readable way.
2017-02-20 Many additions -- SortCup Object++
    * updated types involving resistances to doubles or longs.
    * Added SortCup object which handles logic involving cups
    * completed main loop logic (some changes may be necessary for
    additional features)
    * added feedEmpty function on the StepFeed.
2017-03-18 Sort Wheel Code
    Code for the ATTiny84A driving the Sort Wheel has been added.
2017-03-18 Minor Fixes
    Forgot to check the I2C buffer each loop. Oops.
    [Tiny84_SortWheel.ino]
2017-03-18 Bugfixes
    Fixed several bugs that prevented compiling.
    [ProgmemData.h, RS_Mainboard.ino]
2017-03-19 Minor bugfixes
    Some bugfixes. Current issue: Comms over I2C not working
    [ProgmemData.h, RS_Mainboard.ino, StepFeed.cpp]
2017-03-20 Multiple Fixes. See Description
    Fixed error on Mainboard schematic (SDA and SCL lines swapped!)
    Fixed tabbing on Mainboard ino files
    Began Raspberry Pi scripting
    [RS_Mainboard.ino, ResistorSortUI.py, ResistorSorter.py]
2017-04-01 Testing Phase -- Stepper Attempt 2
2017-04-02 I2C Comms Fixed
    I2C Comms Fixed, along with some debug features.
    [ProgmemData.h, ResistorSortUI.py, ResistorSorter.py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]
2017-04-02 Backlash Compensation, Fixed bug with reverse sort motion, among other minor issues
    [ResistorSortUI.py, SortWheel.cpp, Tiny84_SortWheel.ino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]
2017-04-02 Incorrect Formula
    Fixed issue with incorrect measurement calculation
    [RS_Mainboard.ino]
2017-04-03 Calibration Begins
    Calibrated V-Div ranges (issues remain with 10M and 1M. Ignoring for
    now.)
    [ProgmemData.h, RS_Mainboard.ino]
2017-04-09 Fixed repetitive prompt on UI
    [ResistorSortUI.py]
2017-04-09 Repetitive error 2: Electric Boogaloo.
    [ResistorSortUI.py]
2017-04-14 Completion
    Remaining: Calibration.
2017-04-19 Updated Gerbers, Schematics
    [MainBoard.GBL, MainBoard.GBO, MainBoard.GBP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]
